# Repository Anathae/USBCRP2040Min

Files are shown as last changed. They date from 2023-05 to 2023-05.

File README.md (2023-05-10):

# USBCRP2040MIN
Modified version of the Raspberry Pi (Trading) Ltd. RP2040 Minimal design 
example.

The original USB (B) Micro receptacle has been replaced with a USB C receptacle. 
KiCAD 6.0 has a foot print for the DX07S016JA1R1500 from JAE, and was used here. 
This receptacle breaks out the CC1, CC2, SBU1, and SBU2 pins, but only has the 
D+ and D- pins for USB 1.1 or USB 2.0 data rates. 

SBU1 and SBU2 are broken out, via bridged jumpers, to GPIO1 and GPIO0. CC1 
and CC2 are tied to ground via 5.1k Ohm resisters as required of a UFP for the 
USB C spec, and are also connected, again via bridged jumpers, to GPIO21 and GPIO22.

VBUS, as well as GND are routed to a second 1x2 .1 inch pitch header.

This is intended to be used for prototyping micro controller to micro 
controller communication over the SBU1 and SBU2 pins on the USB C receptacle. 
This does not impliment proper USB C DRP signaling, and may have problems 
acting as a host for other USB devices

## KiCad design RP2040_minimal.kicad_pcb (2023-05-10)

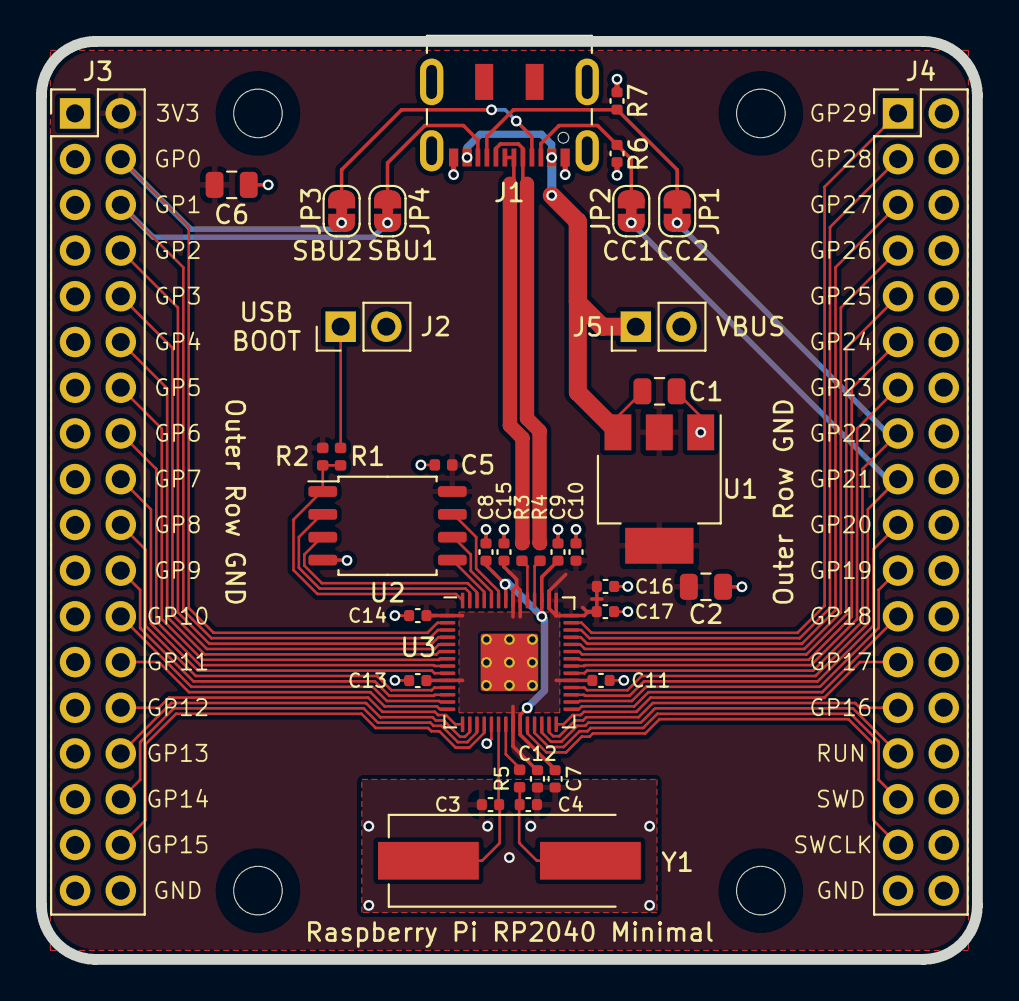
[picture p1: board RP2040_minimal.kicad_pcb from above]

Board: 2 copper layers, 52.0 x 51.0 mm, 41 parts (0 on the bottom side), 55 nets.

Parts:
C1, C2, C6: 10u; C_0805_2012Metric
C3, C4: 27p; C_0402_1005Metric
C5, C7, C8, C11, C12, C13, C14, C15, C16, C17: 100n; C_0402_1005Metric
C9, C10: 1u; C_0402_1005Metric
H1, H2, H3, H4: MountingHole; MountingHole_2.7mm_M2.5
J1: USB_C_Receptacle_USB2.0; USB_C_Receptacle_JAE_DX07S016JA1R1500
J2, J5: Conn_01x02; PinHeader_1x02_P2.54mm_Vertical
J3, J4: Conn_02x18_Odd_Even; PinHeader_2x18_P2.54mm_Vertical
JP1, JP2, JP3, JP4: SolderJumper_2_Bridged; SolderJumper-2_P1.3mm_Bridged_RoundedPad1.0x1.5mm
R1, R5: 1k; C_0402_1005Metric
R2: DNF; C_0402_1005Metric
R3, R4: 27; C_0402_1005Metric
R6, R7: 5k1; C_0402_1005Metric
U1: NCP1117-3.3_SOT223; SOT-223-3_TabPin2
U2: W25Q128JVS; SOIC-8_5.23x5.23mm_P1.27mm
U3: RP2040; RP2040-QFN-56
Y1: ABLS-12.000MHZ-B4-T; Crystal_SMD_HC49-US

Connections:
+1V1: C7.1, C8.1, C9.1, U3.23 (DVDD), U3.45 (VREG_VOUT), U3.50 (DVDD)
+3V3: C2.1, C5.1, C6.1, C10.1, C11.1, C12.1, C13.1, C14.1, C15.1, C16.1, C17.1, J3.2, R2.1, U1.2 (VO), U2.8 (VCC), U3.1 (IOVDD), U3.10 (IOVDD), U3.22 (IOVDD), U3.33 (IOVDD), U3.42 (IOVDD), U3.43 (ADC_AVDD), U3.44 (VREG_IN), U3.48 (USB_VDD), U3.49 (IOVDD)
/CC1: J1.A5 (CC1), JP2.1 (A), R6.2
/CC2: J1.B5 (CC2), JP1.1 (A), R7.2
/GPIO0: J3.4, JP3.2 (B), U3.2 (GPIO0)
/GPIO1: J3.6, JP4.2 (B), U3.3 (GPIO1)
/GPIO2: J3.8, U3.4 (GPIO2)
/GPIO3: J3.10, U3.5 (GPIO3)
/GPIO4: J3.12, U3.6 (GPIO4)
/GPIO5: J3.14, U3.7 (GPIO5)
/GPIO6: J3.16, U3.8 (GPIO6)
/GPIO7: J3.18, U3.9 (GPIO7)
/GPIO8: J3.20, U3.11 (GPIO8)
/GPIO9: J3.22, U3.12 (GPIO9)
/GPIO10: J3.24, U3.13 (GPIO10)
/GPIO11: J3.26, U3.14 (GPIO11)
/GPIO12: J3.28, U3.15 (GPIO12)
/GPIO13: J3.30, U3.16 (GPIO13)
/GPIO14: J3.32, U3.17 (GPIO14)
/GPIO15: J3.34, U3.18 (GPIO15)
/GPIO16: J4.27, U3.27 (GPIO16)
/GPIO17: J4.25, U3.28 (GPIO17)
/GPIO18: J4.23, U3.29 (GPIO18)
/GPIO19: J4.21, U3.30 (GPIO19)
/GPIO20: J4.19, U3.31 (GPIO20)
/GPIO21: J4.17, JP2.2 (B), U3.32 (GPIO21)
/GPIO22: J4.15, JP1.2 (B), U3.34 (GPIO22)
/GPIO23: J4.13, U3.35 (GPIO23)
/GPIO24: J4.11, U3.36 (GPIO24)
/GPIO25: J4.9, U3.37 (GPIO25)
/GPIO26_ADC0: J4.7, U3.38 (GPIO26_ADC0)
/GPIO27_ADC1: J4.5, U3.39 (GPIO27_ADC1)
/GPIO28_ADC2: J4.3, U3.40 (GPIO28_ADC2)
/GPIO29_ADC3: J4.1, U3.41 (GPIO29_ADC3)
/QSPI_SCLK: U2.6 (CLK), U3.52 (QSPI_SCLK)
/QSPI_SD0: U2.5 (DI(IO0)), U3.53 (QSPI_SD0)
/QSPI_SD1: U2.2 (DO(IO1)), U3.55 (QSPI_SD1)
/QSPI_SD2: U2.3 (IO2), U3.54 (QSPI_SD2)
/QSPI_SD3: U2.7 (IO3), U3.51 (QSPI_SD3)
/QSPI_SS: R1.1, R2.2, U2.1 (~CS), U3.56 (QSPI_SS)
/RUN: J4.29, U3.26 (RUN)
/SBU1: J1.A8 (SBU1), JP4.1 (A)
/SBU2: J1.B8 (SBU2), JP3.1 (A)
/SWCLK: J4.33, U3.24 (SWCLK)
/SWD: J4.31, U3.25 (SWD)
/USB_D+: J1.A6 (D+), J1.B6 (D+), R3.1
/USB_D-: J1.A7 (D-), J1.B7 (D-), R4.1
/XIN: C3.1, U3.20 (XIN), Y1.1
/XOUT: R5.1, U3.21 (XOUT)
/~USB_BOOT: J2.1, R1.2
GND: C1.2, C2.2, C3.2, C4.2, C5.2, C6.2, C7.2, C8.2, C9.2, C10.2, C11.2, C12.2, C13.2, C14.2, C15.2, C16.2, C17.2, J1.A1 (GND), J1.A12 (GND), J1.B1 (GND), J1.B12 (GND), J1.S1 (SHIELD), J2.2, J3.1, J3.3, J3.5, J3.7, J3.9, J3.11, J3.13, J3.15, J3.17, J3.19, J3.21, J3.23, J3.25, J3.27, J3.29, J3.31, J3.33, J3.35, J3.36, J4.2, J4.4, J4.6, J4.8, J4.10, J4.12, J4.14, J4.16, J4.18, J4.20, J4.22, J4.24, J4.26, J4.28, J4.30, J4.32, J4.34, J4.35, J4.36, J5.2, R6.1, R7.1, U1.1 (GND), U2.4 (GND), U3.19 (TESTEN), U3.57 (GND)
unnamed: C4.1, R5.2, Y1.2
unnamed: R3.2, U3.47 (USB_DP)
unnamed: R4.2, U3.46 (USB_DM)
VBUS: C1.1, J1.A4 (VBUS), J1.A9 (VBUS), J1.B4 (VBUS), J1.B9 (VBUS), J5.1, U1.3 (VI)

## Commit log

2023-05-06 KiCAD project files in https://datasheets.raspberrypi.com/rp2040/Minimal-KiCAD.zip
    [RP2040_minimal.kicad_pcb, RP2040_minimal.sch]
2023-05-06 .pcb and .sch saved as version kicad 6.0
    [RP2040_minimal.kicad_pcb, RP2040_minimal.kicad_sch]
2023-05-06 Prettied up the component and route placement.
    [RP2040_minimal.kicad_pcb]
2023-05-07 Moved processor, flash, crystal and associated passives towards bottom of board.
    [RP2040_minimal.kicad_pcb]
2023-05-07 Deleted flood fill for VBUS, tightened up passives for 3.3v regulator. Moved 3.3v regulator towards processor.
    [RP2040_minimal.kicad_pcb]
2023-05-07 Updated sheet information, renumbered annotation for capacitors.
    [RP2040_minimal.kicad_pcb, RP2040_minimal.kicad_sch]
2023-05-10 Replaced USB Micro A receptacle with USB C Added 5k1 resistors for UFP identification Added jumpers connecting CC1 to GPIO21, CC2 to GPIO22, SBU2 to GPIO0, and SBU2 to GPIO1. Added jumper for VBUS
    Updated README.md
    [RP2040_minimal.kicad_pcb, RP2040_minimal.kicad_sch]
2023-05-10 Really updated README.md this time.
    [RP2040_minimal.kicad_pcb]
